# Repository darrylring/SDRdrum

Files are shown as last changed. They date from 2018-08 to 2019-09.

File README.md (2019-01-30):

# SDRdrum

SDRdrum is a software-defined radio (SDR) implementation of the Radio Drum: a 3D
gestural capacitive sensor developed at Bell Labs in the 1980s. Originally
created by Bob Boie, one of the pioneers of capacitive sensing, it was intended
to be a 3D computer mouse. Instead, the Radio Drum has found notability as an
instrument for computer music due to the [work][paper] of Max Mathews and
[Andrew Schloss][andy].

While the early Radio Drum implementations used analog signal processing
techniques and 1980s digital electronics, the SDRdrum's signal processing is
completely digital.

[paper]: https://quod.lib.umich.edu/i/icmc/bbp2372.1989.010/--radio-drum-as-a-synthesizer-controller?view=image
[andy]: https://people.finearts.uvic.ca/~aschloss

## License

The SDRdrum's firmware, FPGA logic, and host software (contained within the
`firmware`, `fpga`, and `host` directories respectively) are free software, and
may be modified and redistributed under the terms of the [GNU General Public License][gpl]
(GPL) version 3 or later.

The hardware designs contained in the `boards` directory are licensed under the
[CERN Open Hardware License][ohl] v1.2.

[gpl]: https://www.gnu.org/licenses/gpl-3.0.en.html
[ohl]: https://www.ohwr.org/licenses/cern-ohl/license_versions/v1.2

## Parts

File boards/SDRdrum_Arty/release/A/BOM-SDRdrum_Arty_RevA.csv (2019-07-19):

Designator | LibRef | Quantity | Supplier 1 | Supplier Part Number 1
C1, C3, C5, C7, C22, C24, C26, C28, C32, C34, C36, C38, C47, C48 | CC0402KRX5R6BB105 | 14 | Digi-Key | 311-1439-1-ND
C2, C4, C6, C8 | CC0402KRX7R8BB222 | 4 | Digi-Key | 311-1714-1-ND
C9, C10, C11, C12, C13, C14, C15, C16, C17, C18, C19, C20, C21, C23, C25, C27, C31, C33, C35, C37, C42, C45, C46 | CC0402KRX5R6BB104 | 23 | Digi-Key | 311-1336-1-ND
C29, C30, C39, C40, C41, C49, C51 | CC0805KKX5R6BB106 | 7 | Digi-Key | 311-1460-1-ND
C43, C44 | CC0402DRNPO9BN6R8 | 2 | Digi-Key | 311-1637-1-ND
C50, C52, C53, C54 | CC0805KRX7R8BB224 | 4 | Digi-Key | 311-1432-1-ND
J1, J2, J3, J4, J5, J6 | 5-1814832-1 | 6
J7 | ARTY | 1
R1, R4, R6, R9, R11, R14, R16, R19, R21, R22, R26, R27 | RC0603FR-0710KL | 12 | Digi-Key | 311-10.0KHRCT-ND
R2, R7, R12, R17, R31, R32 | RC0603FR-071KL | 6 | Digi-Key | 311-1.00KHRCT-ND
R3, R8, R13, R18 | RC0603FR-07330RL | 4 | Digi-Key | 311-330HRCT-ND
R5, R10, R15, R20 | RC0603FR-07100KL | 4 | Digi-Key | 311-100KHRCT-ND
R23, R28 | RC0603FR-074K02L | 2 | Digi-Key | 311-4.02KHRCT-ND
R24, R29 | RC0603FR-074K99L | 2 | Digi-Key | 311-4.99KHRCT-ND
R25, R30 | RC0603FR-071KL | 2 | Digi-Key | 311-1.00KHRCT-ND
R33 | RC0603FR-07499RL | 1 | Digi-Key | 311-499HRCT-ND
U1, U2, U3, U4, U5, U6 | TLC082 | 6
U7, U8, U9, U10 | AD7980ARMZ | 4
U11 | AD5545 | 1 | Digi-Key | AD5545BRUZ-ND
U12 | LT1678 | 1 | Digi-Key | LT1678CS8#PBF-ND
U13 | MCP1700T-2502E/TT | 1 | Digi-Key | MCP1700T-2502E/TTCT-ND
U14 | CMR0515S3C | 1 | Digi-Key | 811-2900-5-ND
U15 | PDM1-S5-D5-S | 1
VR1, VR2, VR3, VR4 | 4290W-2K | 4

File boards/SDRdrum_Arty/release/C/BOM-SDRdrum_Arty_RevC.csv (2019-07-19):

Designator | LibRef | Quantity | Supplier 1 | Supplier Part Number 1
C1, C3, C5, C7, C26, C28, C36, C38, C47, C48 | CC0402KRX5R6BB105 | 10 | Digi-Key | 311-1439-1-ND
C2, C4, C6, C8 | CC0402KRX7R8BB222 | 4 | Digi-Key | 311-1714-1-ND
C9, C10, C11, C12, C13, C14, C15, C16, C17, C18, C19, C20, C21, C22, C23, C24, C25, C27, C31, C33, C35, C37, C42, C45, C46 | CC0402KRX5R6BB104 | 25 | Digi-Key | 311-1336-1-ND
C29, C30, C39, C40, C41, C49, C51 | CC0805KKX5R6BB106 | 7 | Digi-Key | 311-1460-1-ND
C32, C34 | CC0603JRNPO9BN101 | 2 | Digi-Key | 311-1069-1-ND
C43, C44 | CC0402DRNPO9BN6R8 | 2 | Digi-Key | 311-1637-1-ND
C50, C52, C53, C54 | CC0805KRX7R8BB224 | 4 | Digi-Key | 311-1432-1-ND
D1 | 150060BS75000 | 1 | Digi-Key | 475-1410-1-ND
D2, D3, D4, D5 | 150066SV74000 | 4
J1, J2, J3, J4, J5, J6 | 0731000105 | 6
J7 | ARTY_1 | 1
J8 | 10029449-111RLF | 1
R1, R4, R6, R9, R11, R14, R16, R19, R21, R22, R26, R27 | RC0603FR-0710KL | 12 | Digi-Key | 311-10.0KHRCT-ND
R2, R7, R12, R17, R31, R32 | RC0603FR-071KL | 6 | Digi-Key | 311-1.00KHRCT-ND
R3, R8, R13, R18 | RC0603FR-07330RL | 4 | Digi-Key | 311-330HRCT-ND
R5, R10, R15, R20, R34, R35, R36, R37, R38 | RC0603FR-07100RL | 9 | Digi-Key | 311-100HRCT-ND
R23 | RC0603FR-070RL | 1 | Digi-Key | 311-0.0HRCT-ND
R24, R29 | RC0603FR-074K99L | 2 | Digi-Key | 311-4.99KHRCT-ND
R25, R30 | RC0603FR-071KL | 2 | Digi-Key | 311-1.00KHRCT-ND
R33 | RC0603FR-07499RL | 1 | Digi-Key | 311-499HRCT-ND
TP_-5V, TP_+2V5, TP_+3V3, TP_+5V, TP_+15V | TP | 5
TP_-15V | TP | 1
U1, U2, U3, U4, U5 | TLC082 | 5
U6, U16 | OPA552 | 2
U7, U8, U9, U10 | AD7980ARMZ | 4
U11 | AD5545 | 1 | Digi-Key | AD5545BRUZ-ND
U12 | LT1678 | 1 | Digi-Key | LT1678CS8#PBF-ND
U13 | MCP1700T-2502E/TT | 1 | Digi-Key | MCP1700T-2502E/TTCT-ND
U14 | CMR0515S3C | 1 | Digi-Key | 811-2900-5-ND
U15 | PDM1-S5-D5-S | 1
VR1, VR2, VR3, VR4 | PV36W204C01B00 | 4
VR5, VR6 | PV36W103C01B00 | 2

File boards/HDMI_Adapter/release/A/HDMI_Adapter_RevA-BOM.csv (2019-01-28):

Designator | LibRef | Quantity | Supplier 1 | Supplier Part Number 1
J1 | 10029449-111RLF | 1
J2 | A-DF 15 A/KG-T2S | 1
R1, R2, R3, R4, R5, R6, R7 | RC0603FR-070RL | 7 | Digi-Key | 311-0.0HRCT-ND
X1, X2, Y1, Y2 | 5-1814832-1 | 4

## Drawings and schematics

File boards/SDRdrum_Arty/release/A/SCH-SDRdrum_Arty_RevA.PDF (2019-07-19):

## Title Page

SDRdrum Arty Shield | Revision: A
Date: 2017-01-08 | Sheet: 1/ 7

# SDRdrum

1
2
3
4
5
6
7

## Title.SchDoc Inputs.SchDoc Outputs.SchDoc ADCs.SchDoc DACs.SchDoc Power.SchDoc Connectors and Mechanical.SchDoc

## Fancy title sheet Input amplification and filtering Output amplification and filtering ADCs DACs and current-to-voltage converters Power supplies Arty FPGA board connector and mechanical components

File Name | Page | Description
Revision | Date | Remarks
A | 2017-01-08 | Initial revision

# Arty Shield

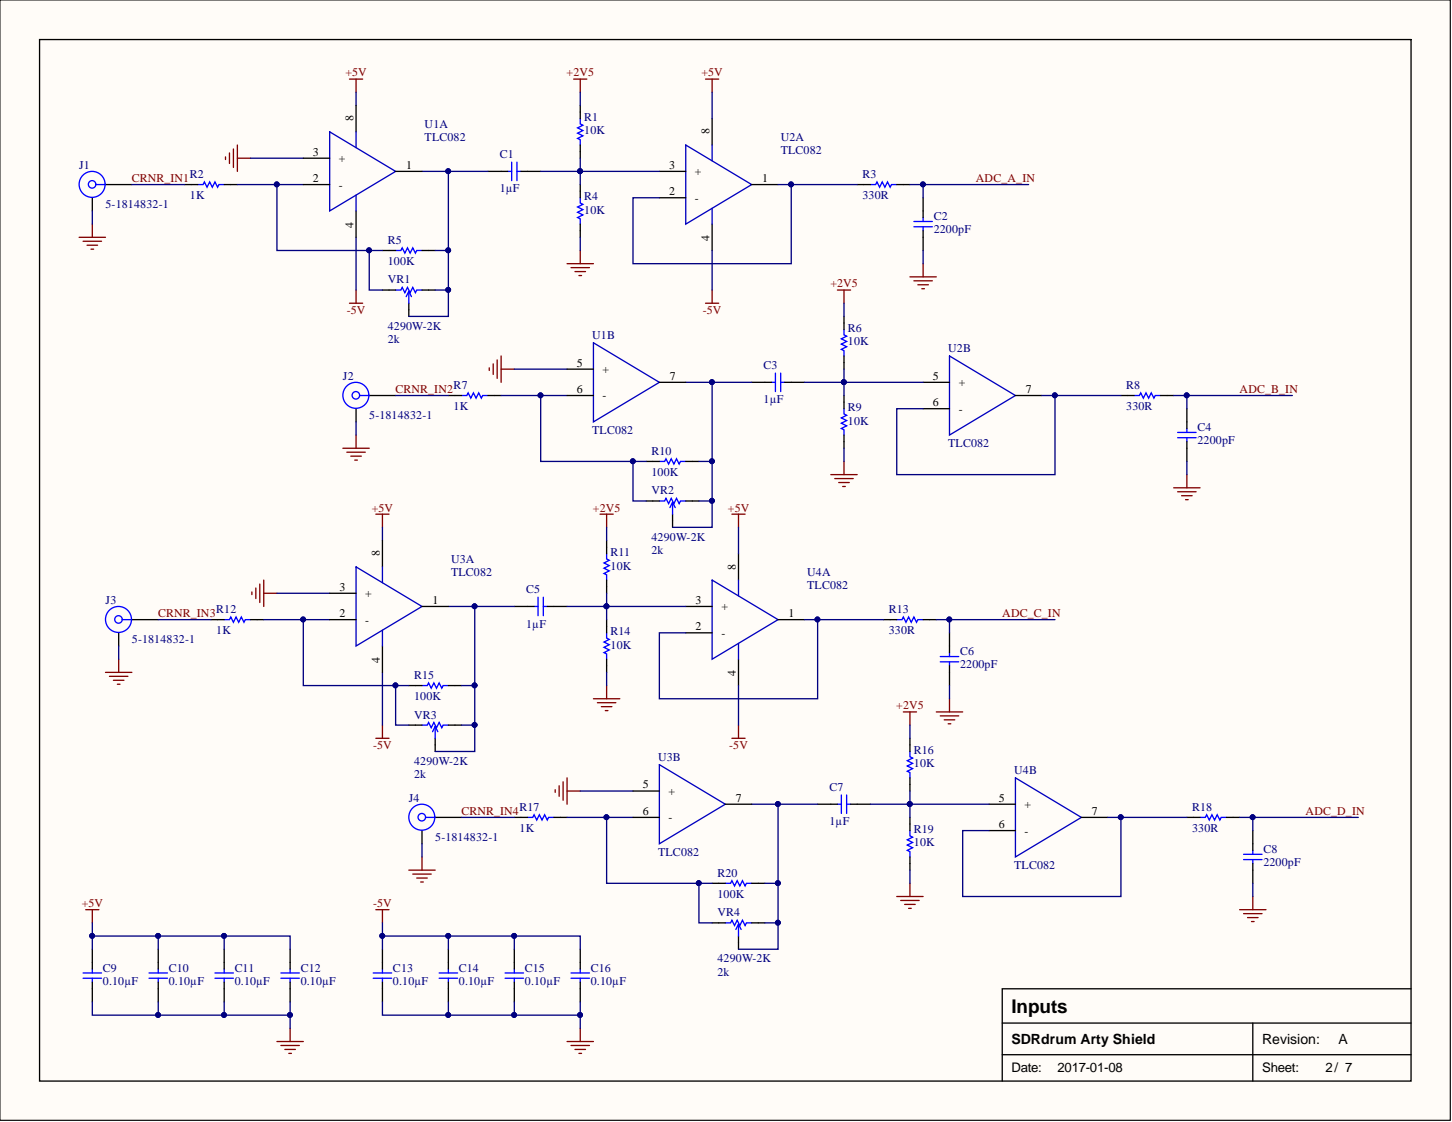
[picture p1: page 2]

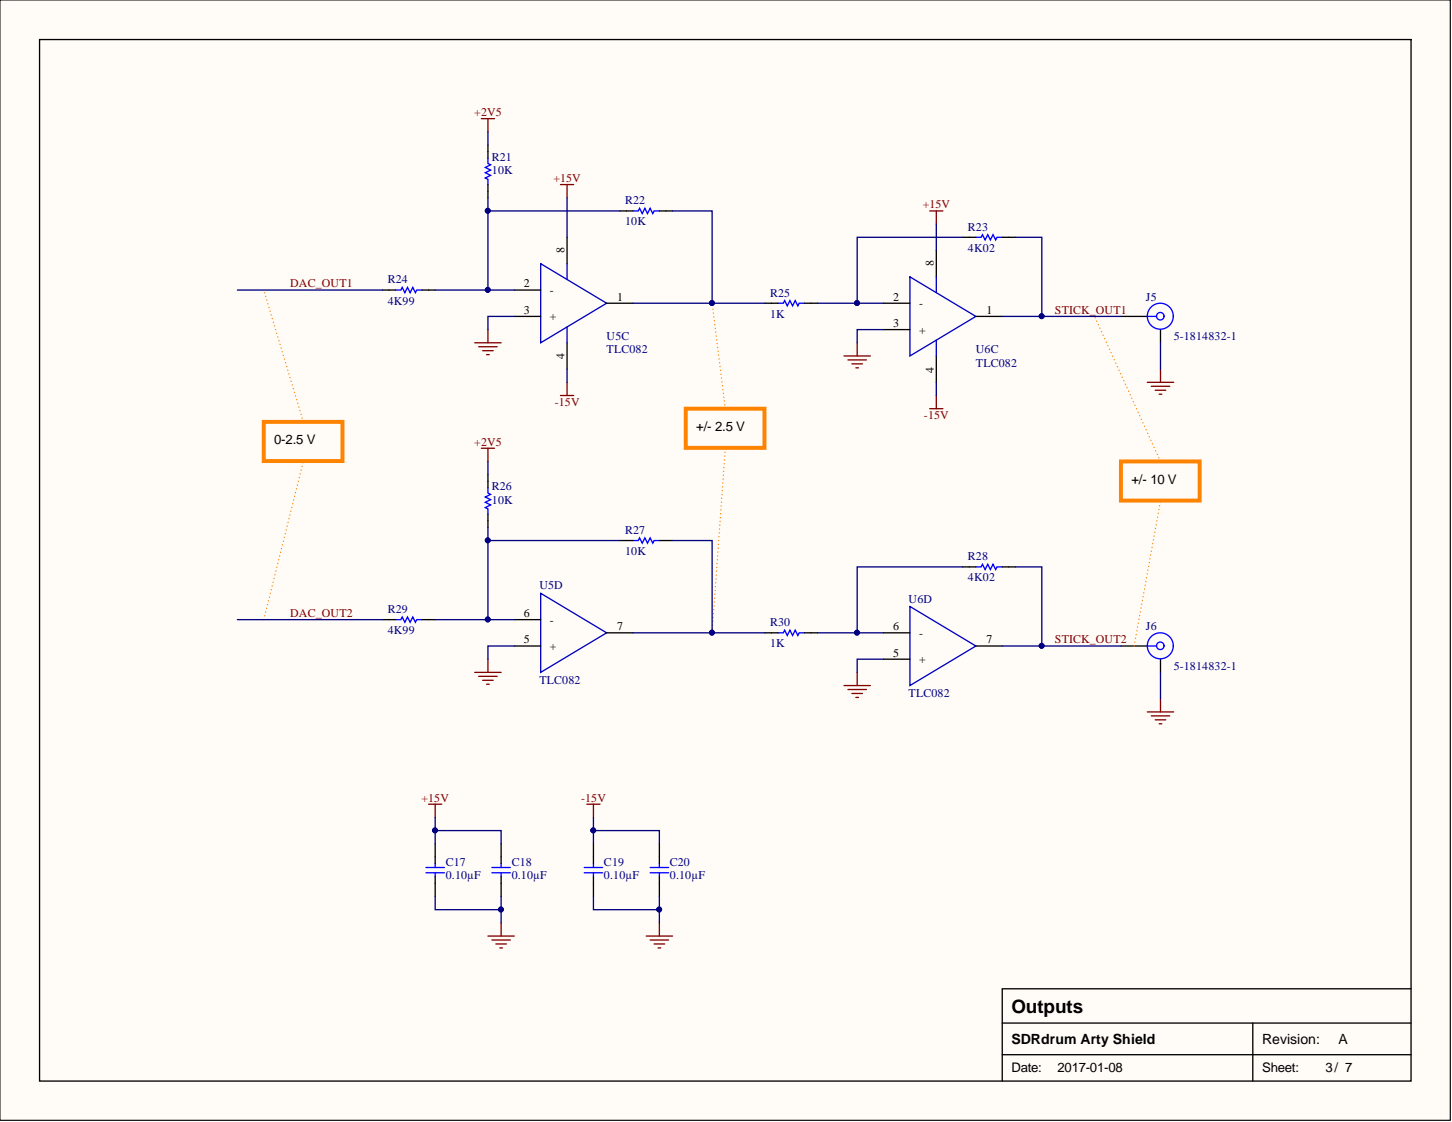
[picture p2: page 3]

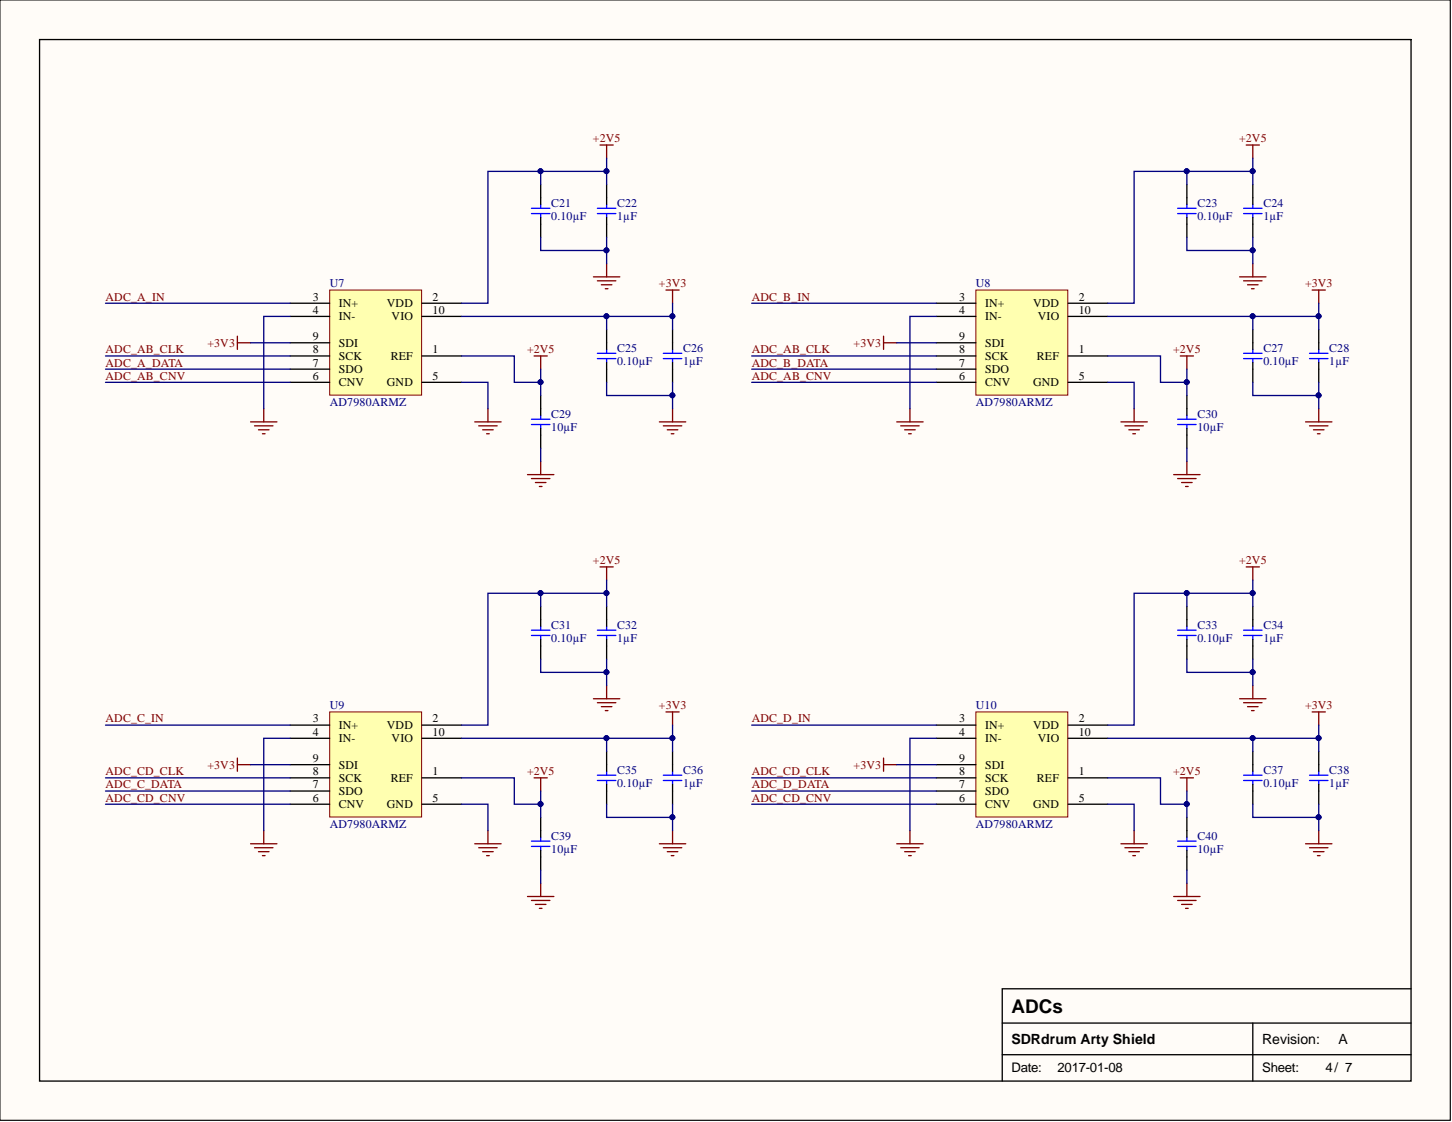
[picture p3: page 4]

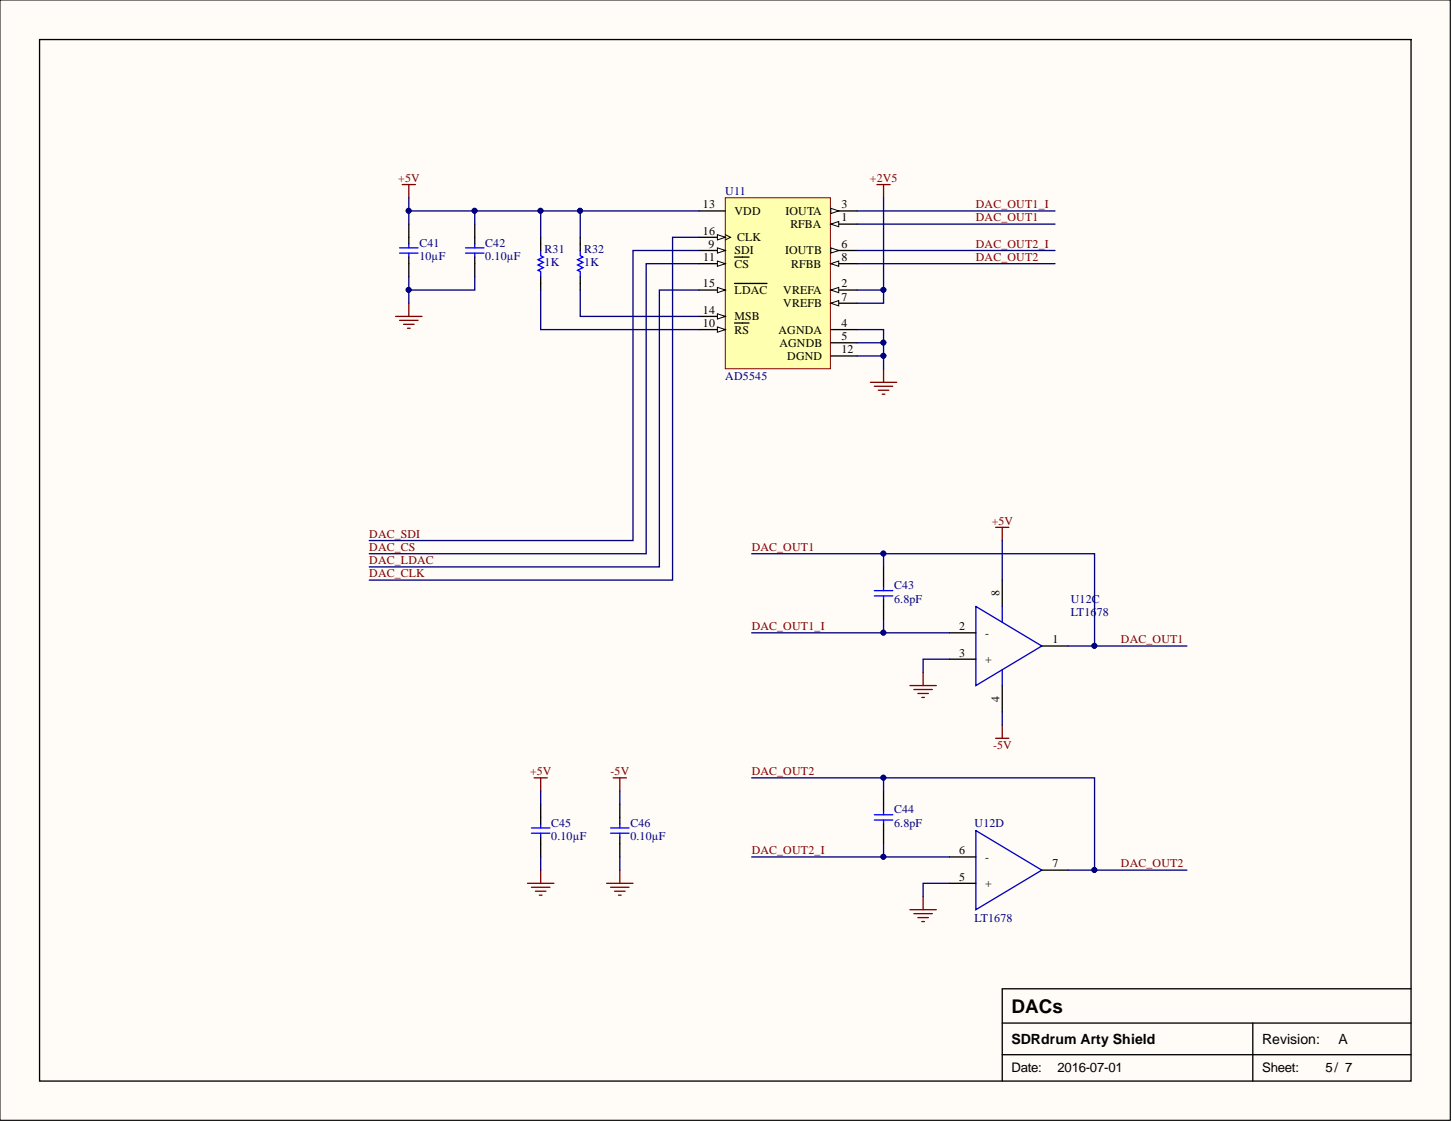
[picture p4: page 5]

CLK 16

C41 C42 R31 R32
10µF 0.10µF | CS 11

LDAC 15

DAC_SDI | MSB 14

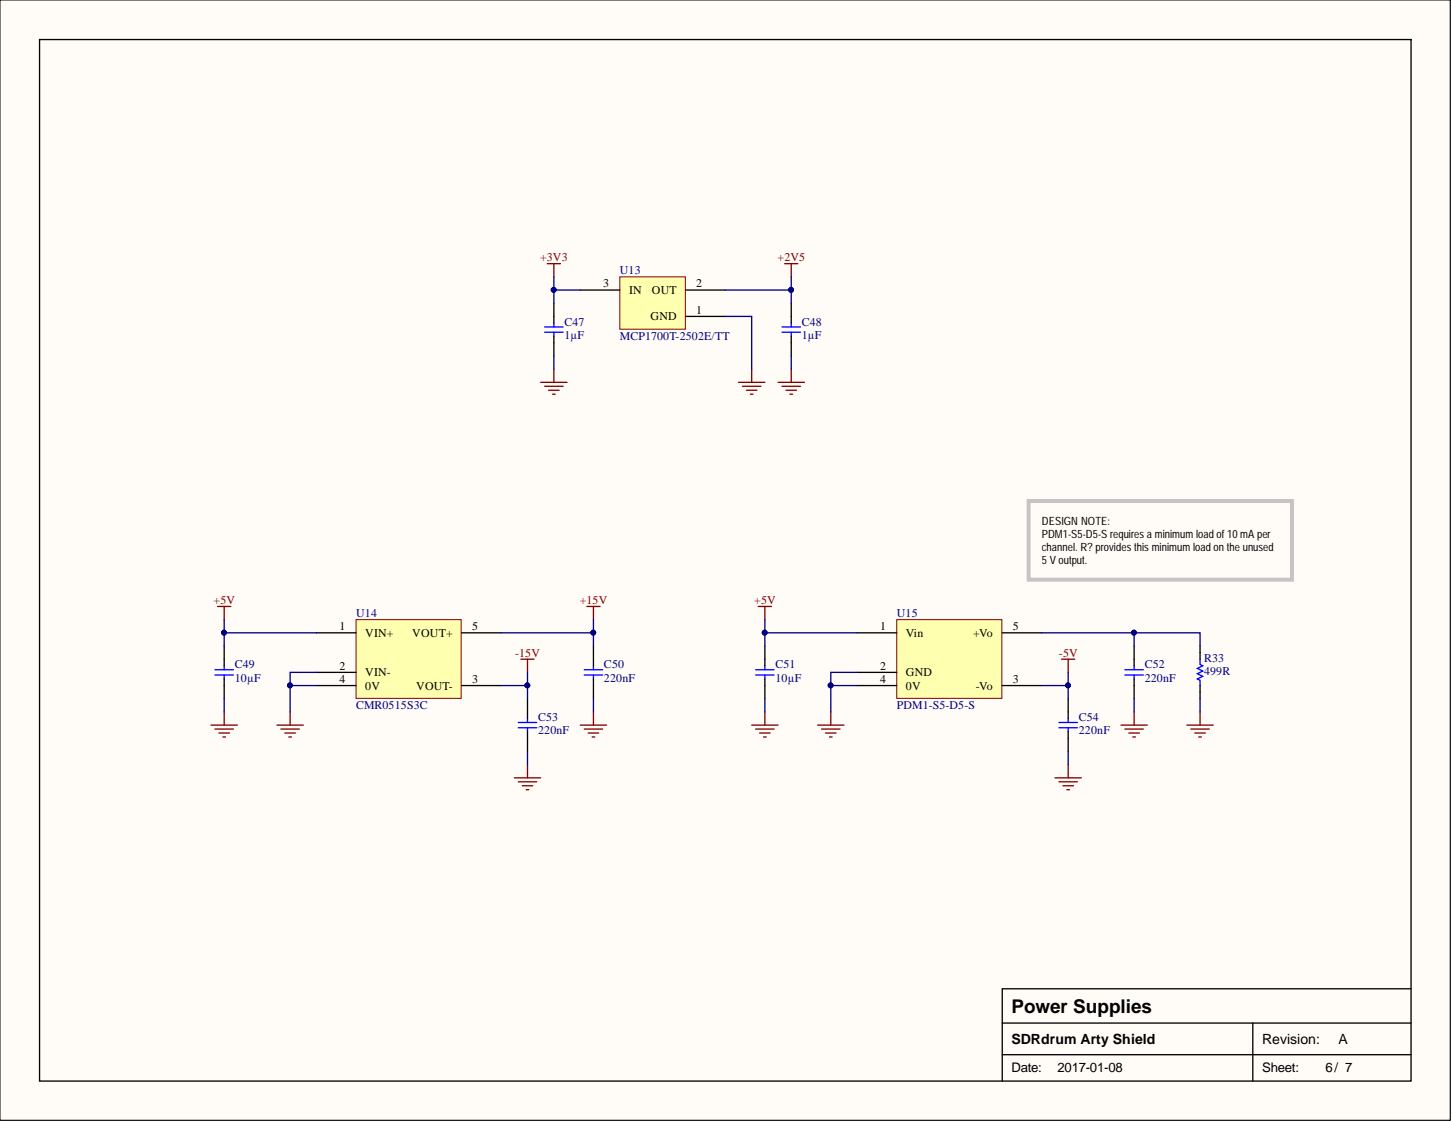
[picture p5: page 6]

DESIGN NOTE:
PDM1-S5-D5-S requires a minimum load of 10 mA per
channel. R? provides this minimum load on the unused
5 V output.

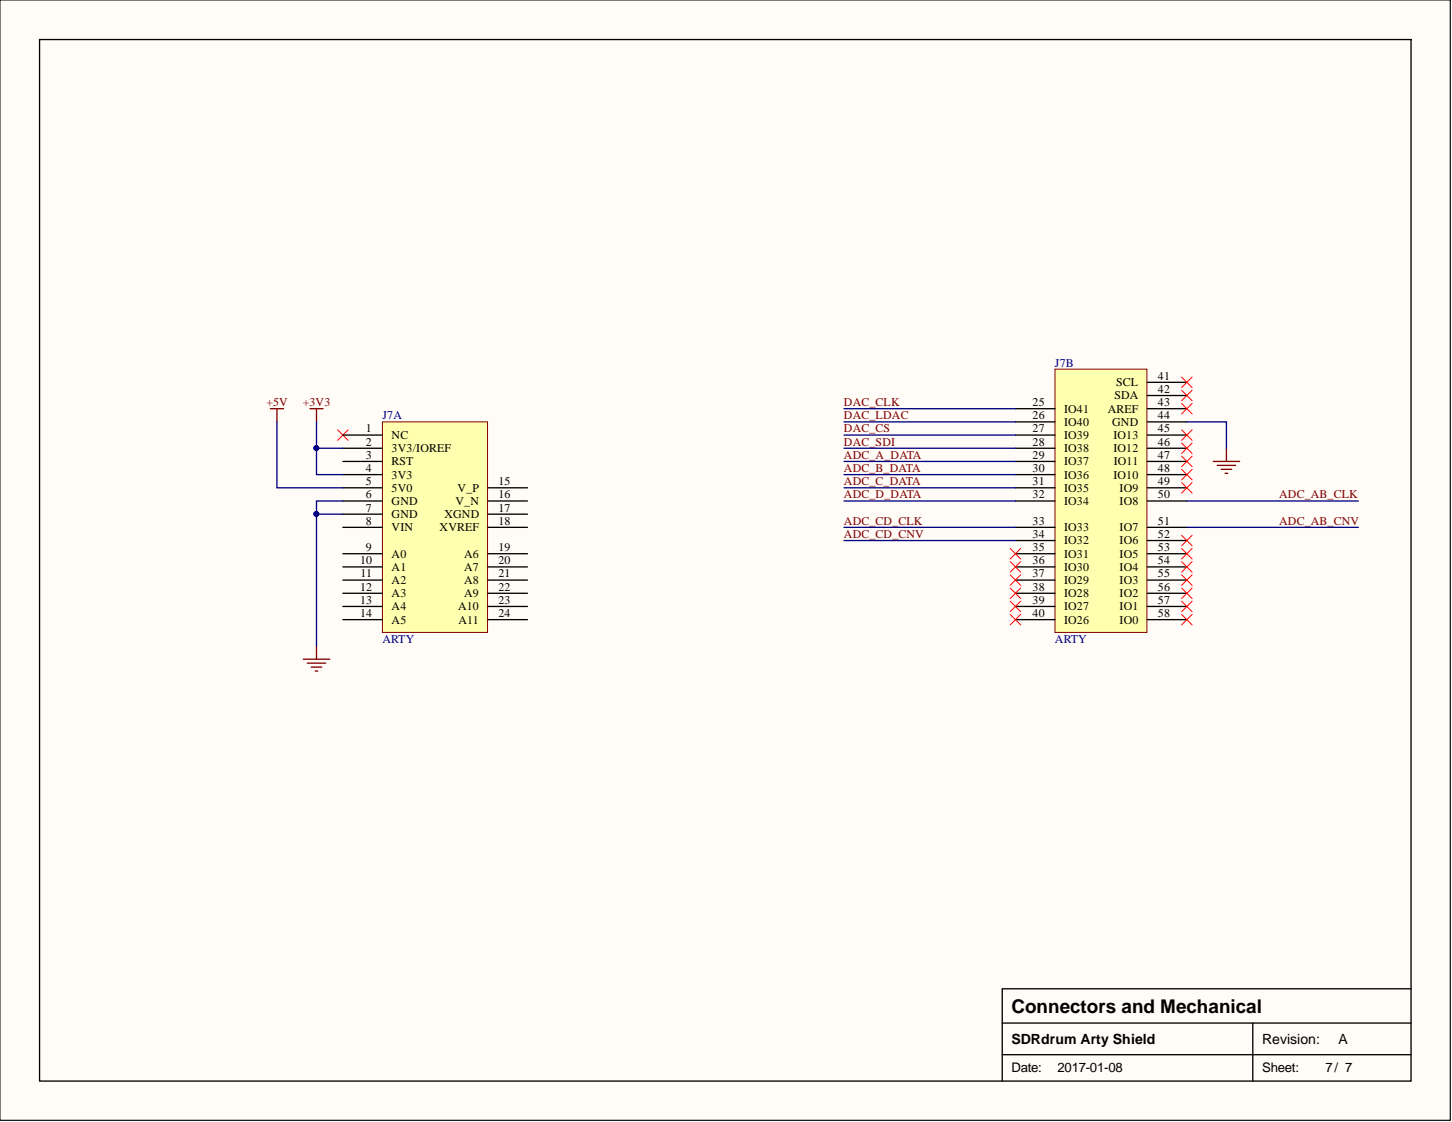
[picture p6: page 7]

Connectors and Mechanical SDRdrum Arty Shield Date: 2017-01-08 | Revision: A

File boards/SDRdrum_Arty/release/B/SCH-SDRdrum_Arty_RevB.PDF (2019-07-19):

## Title Page

SDRdrum Arty Shield | Revision: B
Date: 2019-07-18 | Sheet: 1/ 7

# SDRdrum

1
2
3
4
5
6
7

## Title.SchDoc Inputs.SchDoc Outputs.SchDoc ADCs.SchDoc DACs.SchDoc Power.SchDoc Connectors and Mechanical.SchDoc

## Fancy title sheet Input amplification and filtering Output amplification and filtering ADCs DACs and current-to-voltage converters Power supplies Arty FPGA board connector and mechanical components

File Name | Page | Description
Revision | Date | Remarks

A
B

2017-01-08
2019-07-18

## Initial revision Fixed input gain adjustment, added DAC reconstruction filter capacitors, fixed PCB bugs

# Arty Shield - Rev B

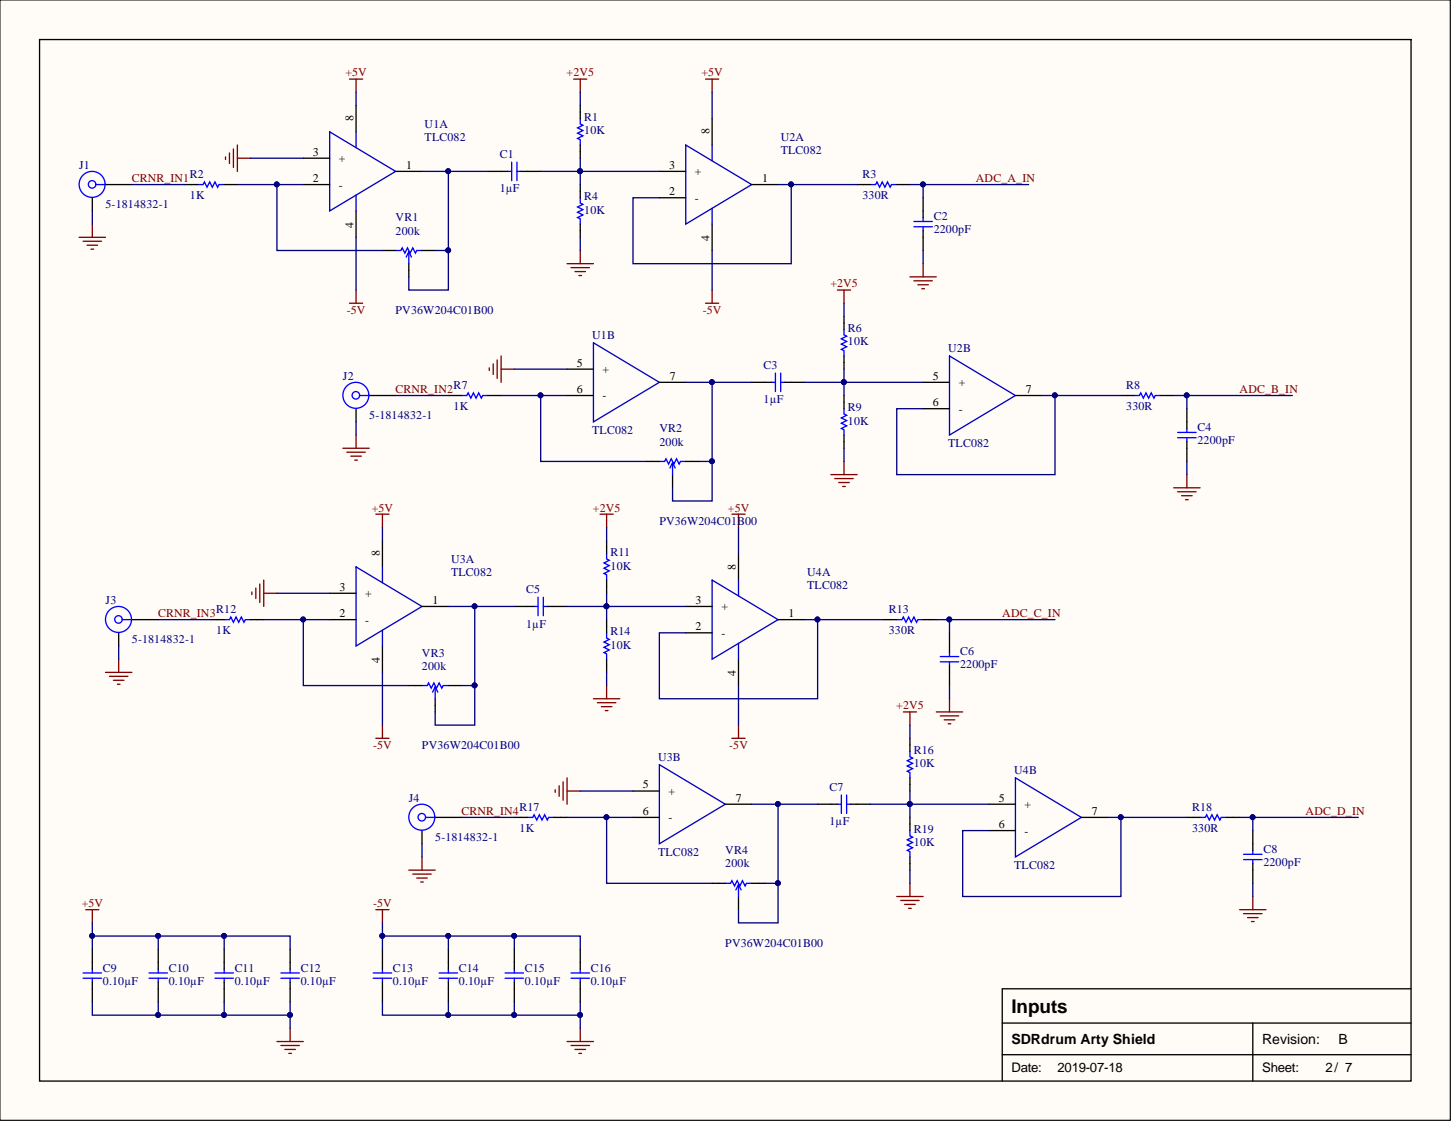
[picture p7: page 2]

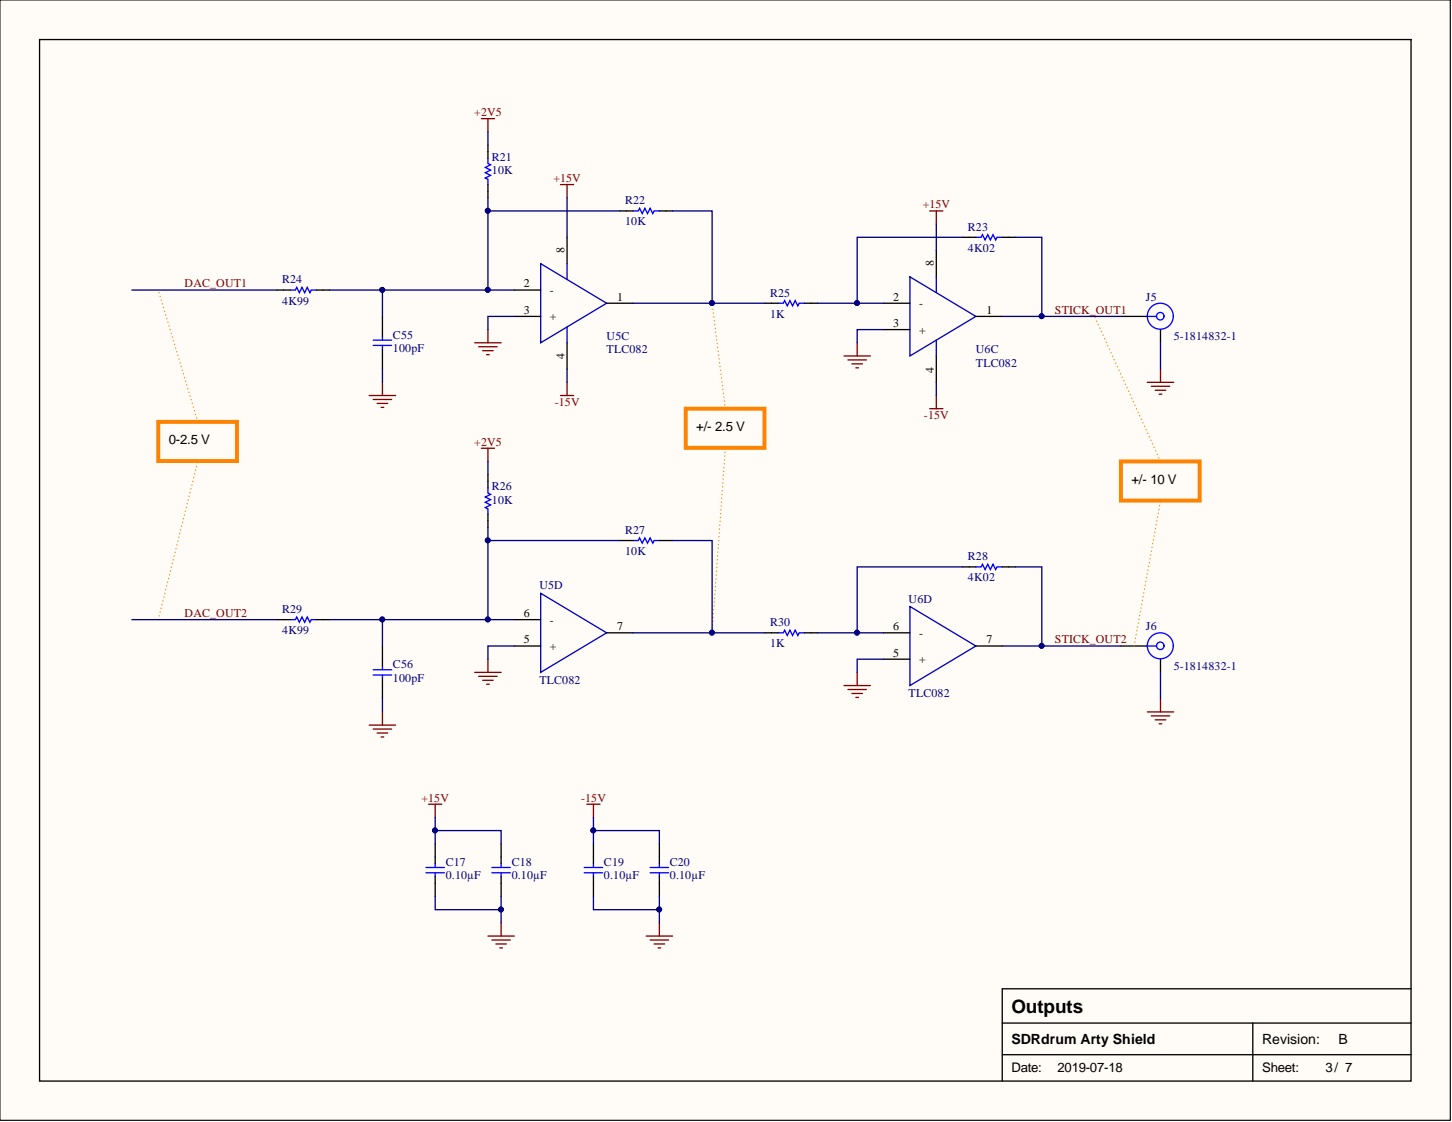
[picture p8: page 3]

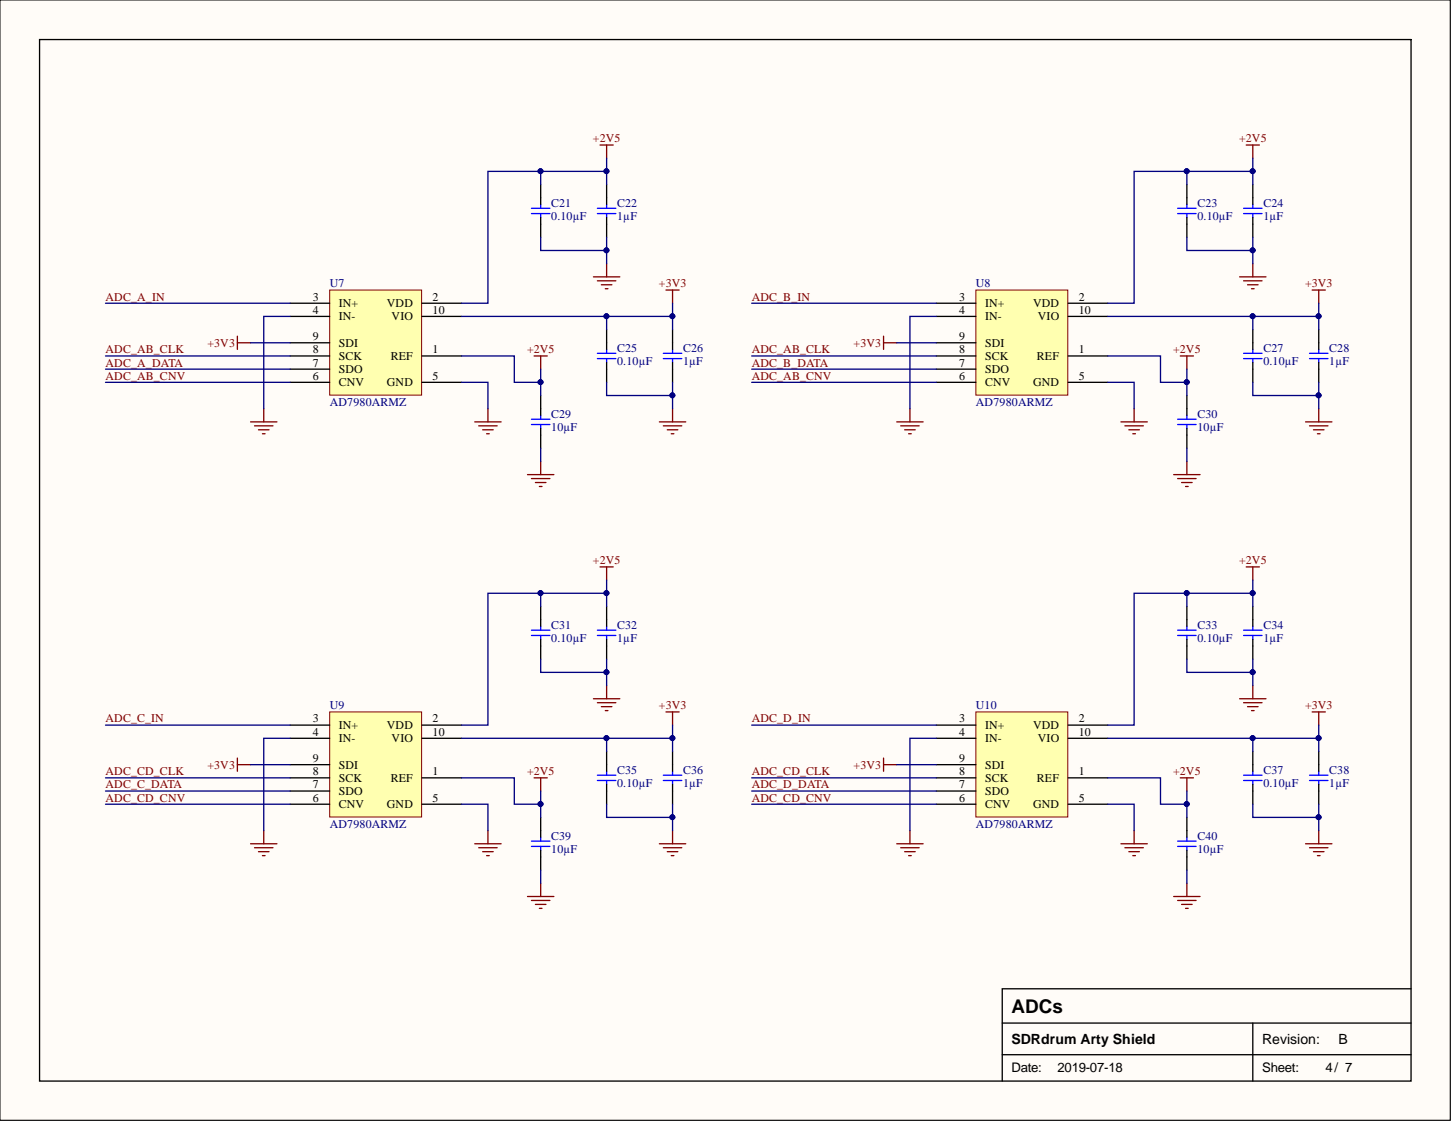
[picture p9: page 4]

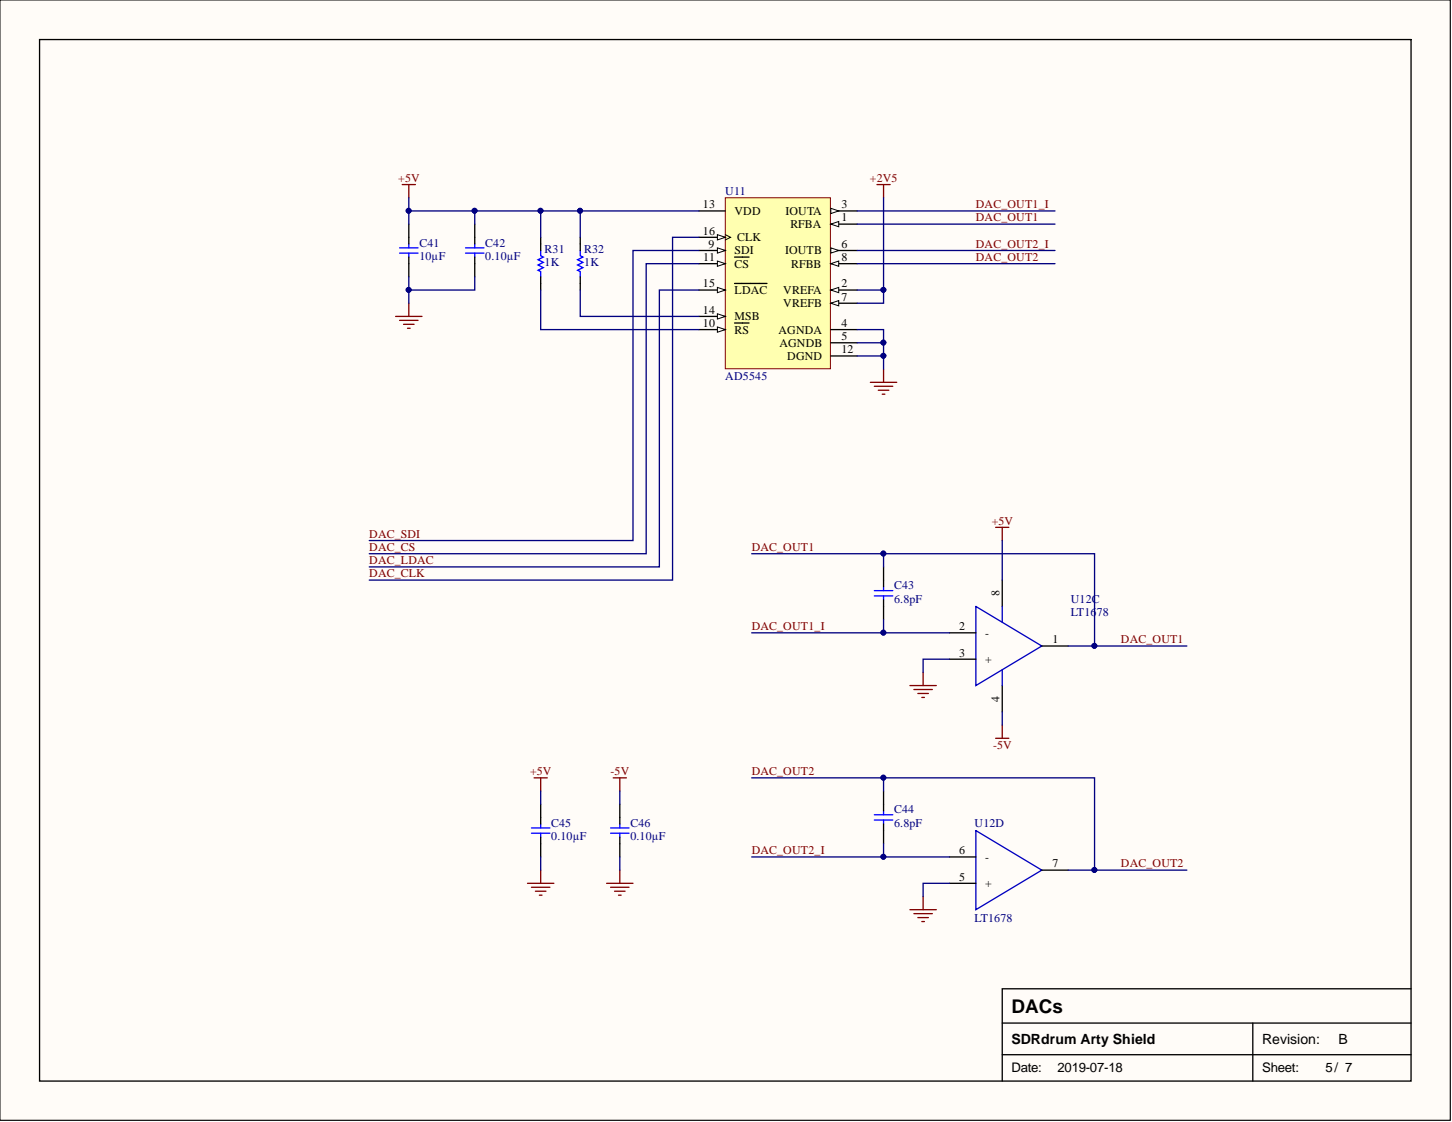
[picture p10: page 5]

CLK 16

C41 C42 R31 R32
10µF 0.10µF | CS 11

LDAC 15

DAC_SDI | MSB 14

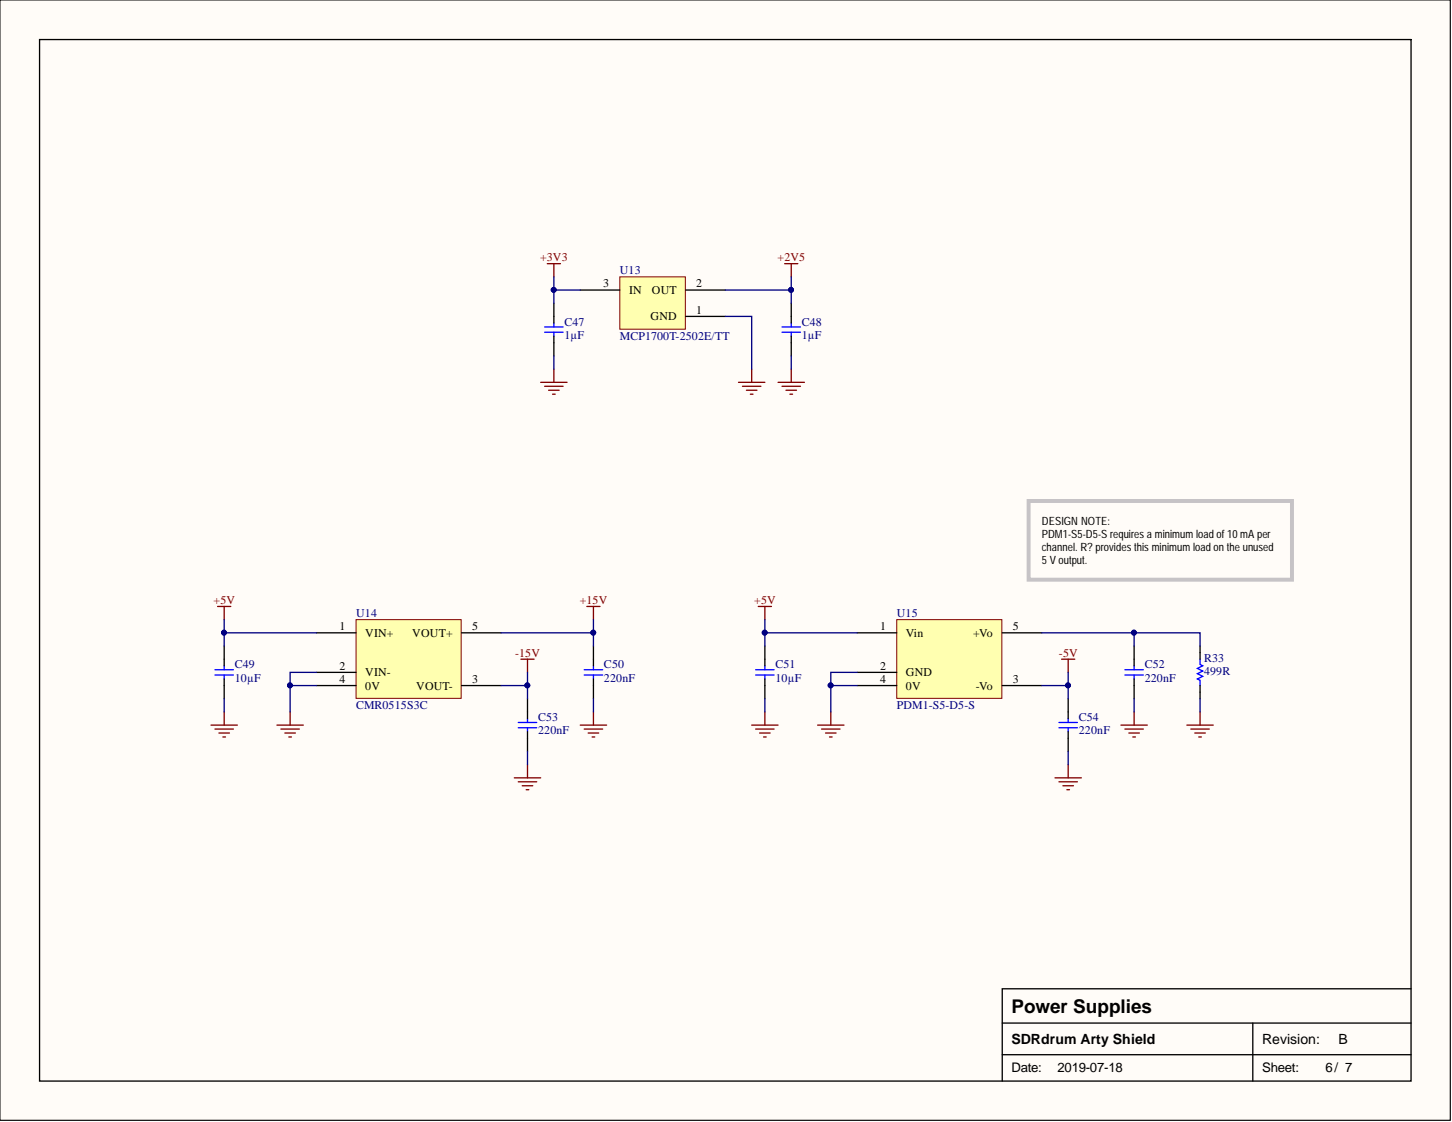
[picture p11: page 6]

DESIGN NOTE:
PDM1-S5-D5-S requires a minimum load of 10 mA per
channel. R? provides this minimum load on the unused
5 V output.

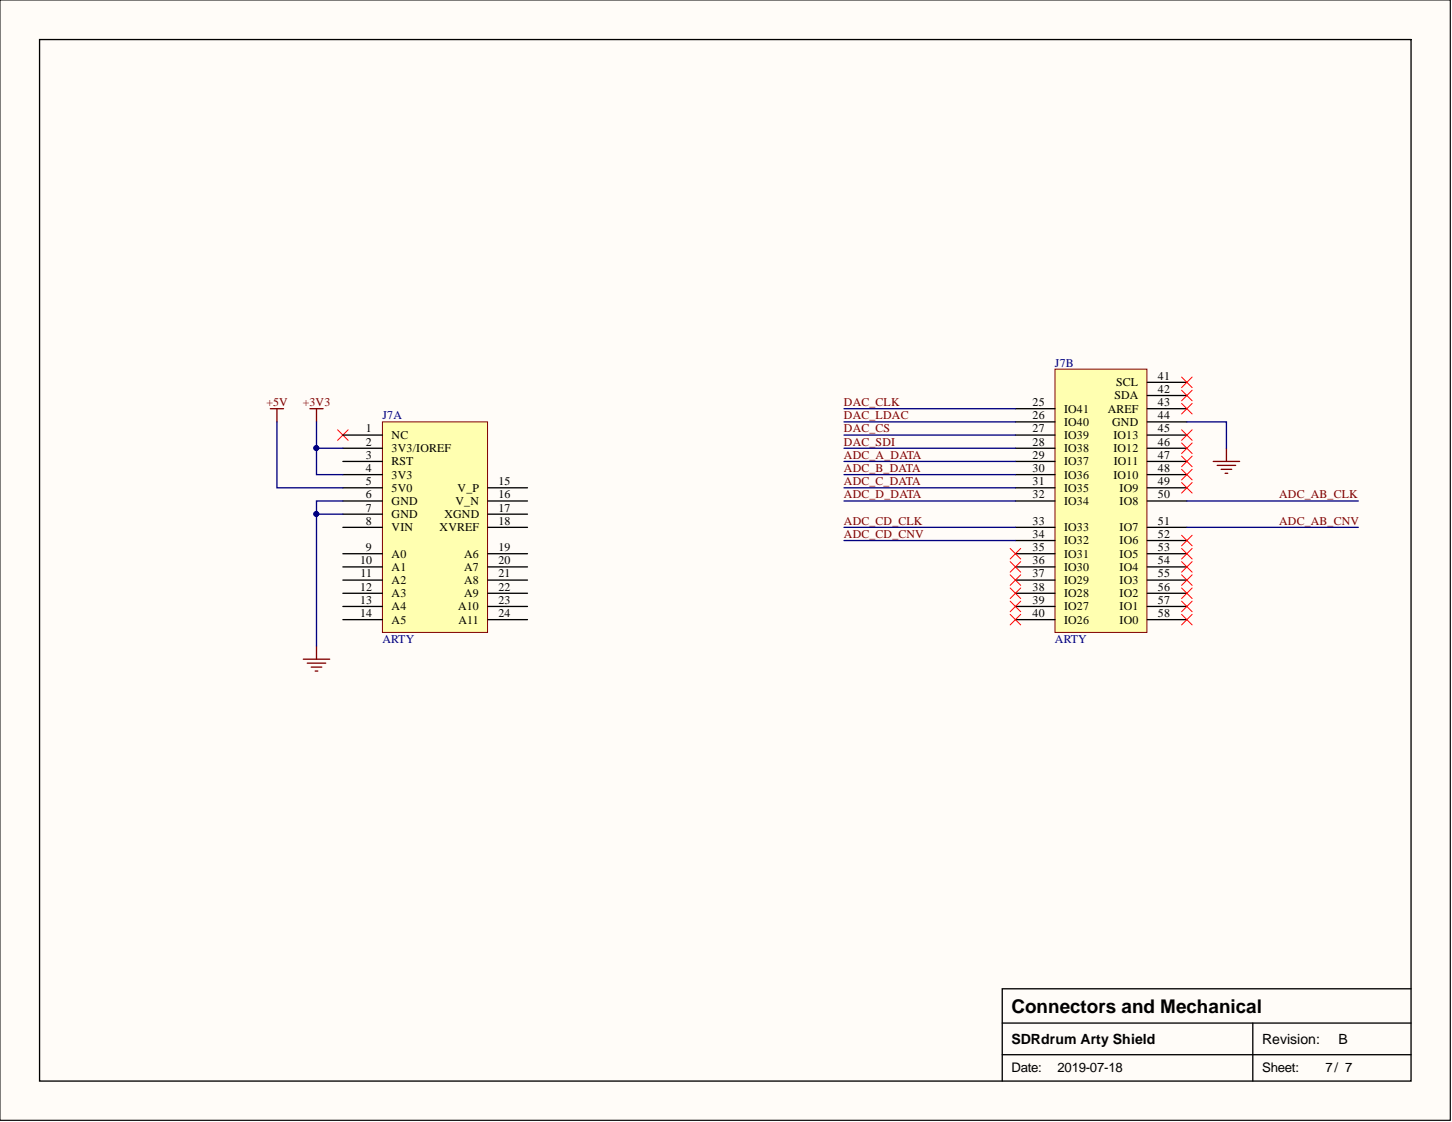
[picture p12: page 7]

Connectors and Mechanical SDRdrum Arty Shield Date: 2019-07-18 | Revision: B

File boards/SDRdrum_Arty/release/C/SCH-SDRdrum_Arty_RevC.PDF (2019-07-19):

## Title Page

SDRdrum Arty Shield | Revision: C
Date: 2019-01-27 | Sheet: 1/ 7

# SDRdrum

1
2
3
4
5
6
7

## Title.SchDoc Inputs.SchDoc Outputs.SchDoc ADCs.SchDoc DACs.SchDoc Power.SchDoc Connectors and Mechanical.SchDoc

## Fancy title sheet Input amplification and filtering Output amplification and filtering ADCs DACs and current-to-voltage converters Power supplies Arty FPGA board connector and mechanical components

File Name | Page | Description
Revision | Date | Remarks

A
B
C

2017-01-08
2019-07-18
2019-01-29

## Initial revision Fixed input gain adjustment, added DAC reconstruction filter capacitors, fixed PCB bugs Switch to BNC and HDMI connectors, add status LEDs, redo PCB layout

# Arty Shield - Rev C





CLK 16

C41 C42 R31 R32
10µF 0.10µF | CS 11

LDAC 15

DAC_SDI | MSB 14


DESIGN NOTE:
PDM1-S5-D5-S requires a minimum load of 10 mA per
channel. R? provides this minimum load on the unused
5 V output.


Connectors and Mechanical SDRdrum Arty Shield Date: 2019-01-27 | Revision: C

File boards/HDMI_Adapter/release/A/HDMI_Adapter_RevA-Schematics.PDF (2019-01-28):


3 4

6 7

9 1 0

1 1 | H DMI_SH L D | | | X 2

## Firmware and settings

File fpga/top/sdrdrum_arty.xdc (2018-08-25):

################################################################################
# Copyright (c) 2018, Darryl Ring.
# 
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
# Additional permission under GNU GPL version 3 section 7:
# If you modify this program, or any covered work, by linking or combining it
# with independent modules provided by the FPGA vendor only (this permission
# does not extend to any 3rd party modules, "soft cores" or macros) under
# different license terms solely for the purpose of generating binary
# "bitstream" files and/or simulating the code, the copyright holders of this
# program give you the right to distribute the covered work without those
# independent modules as long as the source code for them is available from the
# FPGA vendor free of charge, and there is no dependence on any encrypted
# modules for simulating of the combined code. This permission applies to you if
# the distributed code contains all the components and scripts required to
# completely simulate it with at least one of the Free Software programs.

set_property CONFIG_MODE                 SPIx4 [current_design]

set_property BITSTREAM.CONFIG.CONFIGRATE 33    [current_design]
set_property BITSTREAM.GENERAL.COMPRESS  TRUE  [current_design]

set_property -dict { PACKAGE_PIN E3 IOSTANDARD LVCMOS33 } [get_ports { clk_in }];
set_property -dict { PACKAGE_PIN C2 IOSTANDARD LVCMOS33 } [get_ports { rstn_in }];

set_property -dict { PACKAGE_PIN T18 IOSTANDARD LVCMOS33 } [get_ports { dac_data }]; # IO 38
set_property -dict { PACKAGE_PIN R18 IOSTANDARD LVCMOS33 } [get_ports { dac_cs }];   # IO 39
set_property -dict { PACKAGE_PIN P18 IOSTANDARD LVCMOS33 } [get_ports { dac_ldac }]; # IO 40
set_property -dict { PACKAGE_PIN N17 IOSTANDARD LVCMOS33 } [get_ports { dac_clk }];  # IO 41

set_property -dict { PACKAGE_PIN N15 IOSTANDARD LVCMOS33 } [get_ports { adc_ab_clk }]; # IO 8
set_property -dict { PACKAGE_PIN T16 IOSTANDARD LVCMOS33 } [get_ports { adc_ab_cnv }]; # IO 7
set_property -dict { PACKAGE_PIN U17 IOSTANDARD LVCMOS33 } [get_ports { adc_a_data }]; # IO 37
set_property -dict { PACKAGE_PIN N14 IOSTANDARD LVCMOS33 } [get_ports { adc_b_data }]; # IO 36

set_property -dict { PACKAGE_PIN P15 IOSTANDARD LVCMOS33 } [get_ports { adc_cd_clk }]; # IO 33
set_property -dict { PACKAGE_PIN R15 IOSTANDARD LVCMOS33 } [get_ports { adc_cd_cnv }]; # IO 32
set_property -dict { PACKAGE_PIN N16 IOSTANDARD LVCMOS33 } [get_ports { adc_c_data }]; # IO 35
set_property -dict { PACKAGE_PIN R16 IOSTANDARD LVCMOS33 } [get_ports { adc_d_data }]; # IO 34

set_property -dict { PACKAGE_PIN D17 IOSTANDARD LVCMOS33 } [get_ports { eth_phy_col }];
set_property -dict { PACKAGE_PIN G14 IOSTANDARD LVCMOS33 } [get_ports { eth_phy_crs }];
# set_property -dict { PACKAGE_PIN F16 IOSTANDARD LVCMOS33 } [get_ports { eth_phy_mdc }];
# set_property -dict { PACKAGE_PIN K13 IOSTANDARD LVCMOS33 } [get_ports { eth_phy_mdio }];
set_property -dict { PACKAGE_PIN G18 IOSTANDARD LVCMOS33 } [get_ports { eth_phy_clk }];
set_property -dict { PACKAGE_PIN C16 IOSTANDARD LVCMOS33 } [get_ports { eth_phy_rstn }];
set_property -dict { PACKAGE_PIN F15 IOSTANDARD LVCMOS33 } [get_ports { eth_phy_rx_clk }];
set_property -dict { PACKAGE_PIN G16 IOSTANDARD LVCMOS33 } [get_ports { eth_phy_rx_dv }];
set_property -dict { PACKAGE_PIN D18 IOSTANDARD LVCMOS33 } [get_ports { eth_phy_rxd[0] }];
set_property -dict { PACKAGE_PIN E17 IOSTANDARD LVCMOS33 } [get_ports { eth_phy_rxd[1] }];
set_property -dict { PACKAGE_PIN E18 IOSTANDARD LVCMOS33 } [get_ports { eth_phy_rxd[2] }];
set_property -dict { PACKAGE_PIN G17 IOSTANDARD LVCMOS33 } [get_ports { eth_phy_rxd[3] }];
set_property -dict { PACKAGE_PIN C17 IOSTANDARD LVCMOS33 } [get_ports { eth_phy_rx_er }];
set_property -dict { PACKAGE_PIN H16 IOSTANDARD LVCMOS33 } [get_ports { eth_phy_tx_clk }];
set_property -dict { PACKAGE_PIN H15 IOSTANDARD LVCMOS33 } [get_ports { eth_phy_tx_en }];
set_property -dict { PACKAGE_PIN H14 IOSTANDARD LVCMOS33 } [get_ports { eth_phy_txd[0] }];
set_property -dict { PACKAGE_PIN J14 IOSTANDARD LVCMOS33 } [get_ports { eth_phy_txd[1] }];
set_property -dict { PACKAGE_PIN J13 IOSTANDARD LVCMOS33 } [get_ports { eth_phy_txd[2] }];
set_property -dict { PACKAGE_PIN H17 IOSTANDARD LVCMOS33 } [get_ports { eth_phy_txd[3] }];

set_property -dict { PACKAGE_PIN A9  IOSTANDARD LVCMOS33 } [get_ports { usb_uart_rxd }];
set_property -dict { PACKAGE_PIN D10 IOSTANDARD LVCMOS33 } [get_ports { usb_uart_txd }];

set_property -dict { PACKAGE_PIN A8  IOSTANDARD LVCMOS33 } [get_ports { switches[0] }];
set_property -dict { PACKAGE_PIN C11 IOSTANDARD LVCMOS33 } [get_ports { switches[1] }];
set_property -dict { PACKAGE_PIN C10 IOSTANDARD LVCMOS33 } [get_ports { switches[2] }];
set_property -dict { PACKAGE_PIN A10 IOSTANDARD LVCMOS33 } [get_ports { switches[3] }];
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

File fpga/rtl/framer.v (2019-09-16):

////////////////////////////////////////////////////////////////////////////////
// 
//  Copyright (c) 2018, Darryl Ring.
// 
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
//  Additional permission under GNU GPL version 3 section 7:
//  If you modify this program, or any covered work, by linking or combining it
//  with independent modules provided by the FPGA vendor only (this permission
//  does not extend to any 3rd party modules, "soft cores" or macros) under
//  different license terms solely for the purpose of generating binary
//  "bitstream" files and/or simulating the code, the copyright holders of this
//  program give you the right to distribute the covered work without those
//  independent modules as long as the source code for them is available from
//  the FPGA vendor free of charge, and there is no dependence on any encrypted
//  modules for simulating of the combined code. This permission applies to you
//  if the distributed code contains all the components and scripts required to
//  completely simulate it with at least one of the Free Software programs.
//
////////////////////////////////////////////////////////////////////////////////


`timescale 1ns / 1ps

module framer (
    // Clock and Reset
    input  wire        aclk,
    input  wire        aresetn,
    
    // Input data stream
    input  wire [255:0] s_axis_tdata,
    input  wire         s_axis_tvalid,
    output wire         s_axis_tready,

    // Frame output
    output wire [31:0] m_axi_awaddr,
    output wire        m_axi_awvalid,
    input  wire        m_axi_awready,

    output wire [31:0] m_axi_wdata,
    output wire [3:0]  m_axi_wstrb,
    output wire        m_axi_wvalid,
    input  wire        m_axi_wready,

    input  wire [1:0]  m_axi_bresp,
    input  wire        m_axi_bvalid,
    output wire        m_axi_bready,

    output wire [31:0] m_axi_araddr,
    output wire        m_axi_arvalid,
    input  wire        m_axi_arready,

    input  wire [31:0] m_axi_rdata,
    input  wire [1:0]  m_axi_rresp,
    input  wire        m_axi_rvalid,
    output wire        m_axi_rready
);

localparam [2:0]
    STATE_INIT        = 3'd0,
    STATE_IDLE        = 3'd1,
    STATE_WRITE_FRAME = 3'd2,
    STATE_TX_FRAME    = 3'd3,
    STATE_WAIT_DONE   = 3'd4;

reg [255:0] data;
reg [255:0] data_next;

reg  [2:0] state;
reg  [2:0] state_next;

reg         tready_reg;
reg  [31:0] awaddr_reg;
reg         awvalid_reg;
reg  [31:0] wdata_reg;
reg         wvalid_reg;
reg  [31:0] araddr_reg;
reg         arvalid_reg;
reg         rready_reg;

reg         tready_next;
reg  [31:0] awaddr_next; 
reg         awvalid_next;
reg  [31:0] wdata_next;
reg         wvalid_next;
reg  [31:0] araddr_next;
reg         arvalid_next;
reg         rready_next;


always @* begin
    state_next = STATE_IDLE;
    
    data_next = data;

    tready_next = tready_reg;
    
    awaddr_next = awaddr_reg;
    awvalid_next = awvalid_reg;
    
    wdata_next = wdata_reg;
    wvalid_next = wvalid_reg;
    
    araddr_next = araddr_reg;
    arvalid_next = arvalid_reg;
    
    rready_next = rready_reg;
    
    case (state)
        STATE_INIT: begin
            awaddr_next = 32'h40E0_07f4;
            wdata_next = 32'h0062;
            
            if (m_axi_awready) begin
                if (m_axi_awvalid) begin
                    awvalid_next = 1'b0;
                    wvalid_next = 1'b1;
                end
            end else begin
                if (!m_axi_wvalid) awvalid_next = 1'b1;
            end
            
            if (m_axi_wready) begin
                if (m_axi_wvalid) begin
                    awaddr_next = 32'h40E0_0000;
                    awvalid_next = 1'b0;
                    wvalid_next = 1'b0;
                    wdata_next = 32'b0;
                    state_next = STATE_IDLE;
                end else begin
                    state_next = STATE_INIT;
                end
            end else begin
                state_next = STATE_INIT;
            end
        end
        STATE_IDLE: begin
            if (s_axis_tready & s_axis_tvalid) begin
                data_next = s_axis_tdata;
                tready_next = 1'b0;
                awaddr_next = 32'h40E0_0000;
                awvalid_next = 1'b1;
                rready_next = 1'b0;
                state_next = STATE_WRITE_FRAME;
            end else begin
                tready_next = 1'b1;
                rready_next = 1'b1;

                state_next = STATE_IDLE;
            end
        end
        STATE_WRITE_FRAME: begin
            state_next = STATE_WRITE_FRAME;

            case (m_axi_awaddr[12:0])
                13'h00: wdata_next = 32'hFFFFFFFF;
                13'h04: wdata_next = 32'h1800FFFF;
                13'h08: wdata_next = 32'h6b4d023e;
                13'h0c: wdata_next = 32'h00450008;
                13'h10: wdata_next = 32'h00005400;
                13'h14: wdata_next = 32'h11ff0000;
                13'h18: wdata_next = 32'h0000eff0;
                13'h1c: wdata_next = 32'ha8c00000;
                13'h20: wdata_next = 32'hc507010a;
                13'h24: wdata_next = 32'h4000c507;
                13'h28: wdata_next = 32'h722f0000;
                13'h2c: wdata_next = 32'h6f696461;
                13'h30: wdata_next = 32'h6d757264;
                13'h34: wdata_next = 32'h692c0000;
                13'h38: wdata_next = 32'h69696969;
                13'h3c: wdata_next = 32'h00696969;
                
                13'h40: wdata_next = {data[23:16], data[31:24], 16'h0000};
                13'h44: wdata_next = {data[55:48], data[63:56], data[7:0], data[15:8]};
                13'h48: wdata_next = {data[87:80], data[95:88], data[39:32], data[47:40]};
                13'h4c: wdata_next = {data[119:112], data[127:120], data[71:64], data[79:72]};
                13'h50: wdata_next = {data[151:144], data[159:152], data[103:96], data[111:104]};
                
                13'h54: wdata_next = {data[183:176], data[191:184], data[135:128], data[143:136]};
                13'h58: wdata_next = {data[215:208], data[223:216], data[167:160], data[175:168]};
                13'h5c: wdata_next = {data[247:240], data[255:248], data[199:192], data[207:200]};
                13'h60: wdata_next = {16'h0000, data[231:224], data[239:232]};
            endcase
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

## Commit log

2016-11-26 Add prototype FPGA code
2017-02-20 Add Arty SDRdrum hardware design
    [ADCs.SchDoc, Bill of Materials-SDRdrum Arty.csv, Connectors and Mechanical.SchDoc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]
2017-03-15 Update DSP
    Decimate by 1024 instead of 1000 to have whole-number bit gain in CIC
    filters. Carry extra bits through the DSP chain to maintain dynamic
    range. Fix phase generator reset behaviour for simulation.
2017-03-15 Add MicroBlaze controller
    MicroBlaze and framer access MAC through an AXI interconnect, which
    changes the AXI behaviour slightly. The framer has been updated to
    account for these changes. The controller has GPIOs to interact with
    the DSP chain as well as the LEDs and switches on the Arty board.
2018-03-12 Move Arty board files
    [ADCs.SchDoc, Bill of Materials-SDRdrum Arty.csv, Connectors and Mechanical.SchDoc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]
2018-03-13 Add SDRdrum board
    [ADCs.SchDoc, Block Diagram.SchDoc, Connectors and Mechanical.SchDoc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]
2018-10-01 Reorganize boards, libraries
    [ADCs.SchDoc, Antenna_22x16_RevA.PcbDoc, Bill of Materials-SDRdrum Arty.csv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]
2019-01-26 boards: Fix SDRdrum Arty rev B design
    [Connectors and Mechanical.SchDoc, Inputs.SchDoc, SDRdrum_Arty_RevB.PrjPcb]
2019-01-27 boards: Complete SDRdrum Arty rev B design
    [Connectors and Mechanical.SchDoc, Outputs.SchDoc, SDRdrum_Arty_RevB.PrjPcb]
2019-01-27 boards: Release SDRdrum Arty rev B
    [ADCs.SchDoc, Bill of Materials-SDRdrum_Arty_RevB.csv, Connectors and Mechanical.SchDoc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]
2019-01-28 boards: Complete HDMI Adapter rev A
    [HDMI_Adapter_RevA.PcbDoc, HDMI_Adapter_RevA.PrjPCB, HDMI_Adapter_RevA.SchDoc]
2019-01-28 boards: Release HDMI Adapter rev A
    [HDMI_Adapter_RevA-BOM.csv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]
2019-01-30 Add output gain adjust, re-release rev B
    [Bill of Materials-SDRdrum_Arty_RevB.csv, Connectors and Mechanical.SchDoc, HDMI_Adapter_RevA-BOM.csv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]
2019-02-27 Add 21x18 inch antenna pad design
    [Antenna_21x18_RevA.PcbDoc, Antenna_21x18_RevA.PrjPcb]
2019-07-19 boards: Release SDRdrum Arty Rev B, rename old rev B to C
    Fix structure, output job files, etc.
    [ADCs.SchDoc, BOM-SDRdrum_Arty_RevA.csv, BOM-SDRdrum_Arty_RevB.csv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]
2019-09-15 Fix invalid phase input, MAC address
    [framer.v]
2019-09-16 Fix Ethernet MAC addressing
    [framer.v]

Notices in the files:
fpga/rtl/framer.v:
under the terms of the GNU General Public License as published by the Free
